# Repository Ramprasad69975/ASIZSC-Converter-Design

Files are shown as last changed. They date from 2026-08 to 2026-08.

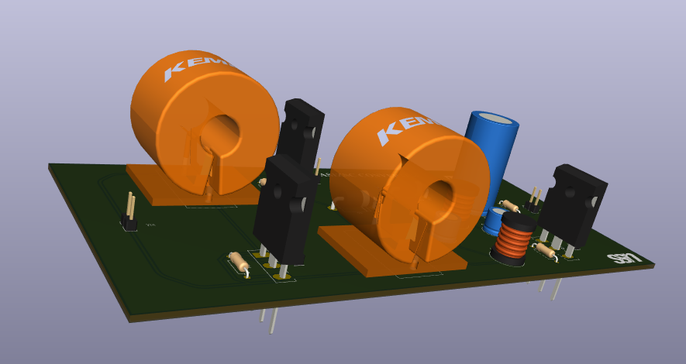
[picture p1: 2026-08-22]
PCB Images/3D Model.png

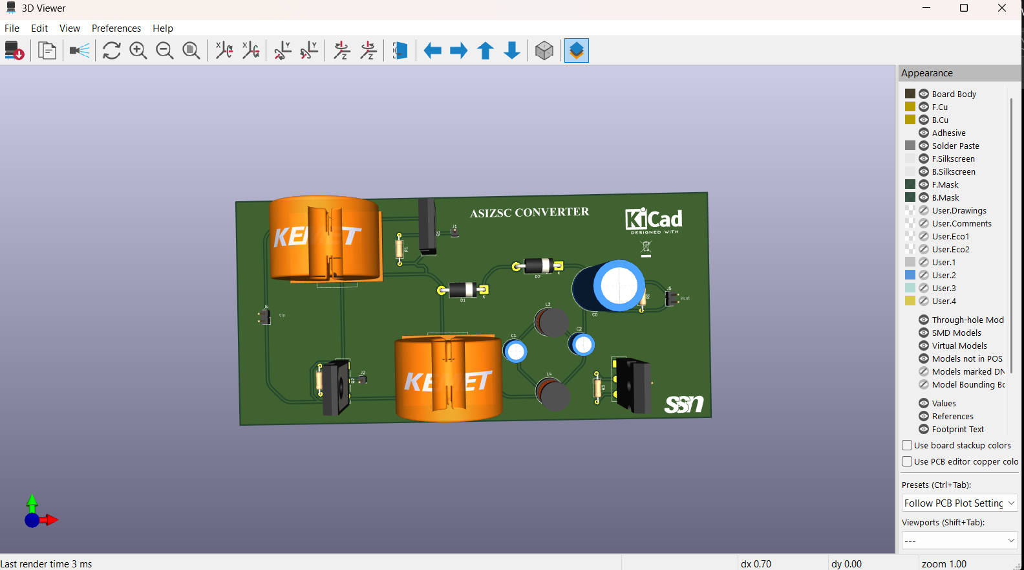
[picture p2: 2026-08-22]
PCB Images/3D view.png

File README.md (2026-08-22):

# ASIZSC Converter – Simulation & PCB Design

## Overview

This project documents the step-by-step development of a power electronics converter, starting from a basic Boost Converter and progressing toward the design of an Advanced Switched-Inductor Z-Source Converter (ASIZSC).

The work was carried out in three major stages:

1. Basic Boost Converter design and analysis
2. ASIZSC converter modelling and simulation in MATLAB/Simulink
3. Schematic and PCB design of the ASIZSC converter using KiCad

The project helped in understanding the transition from converter-level concepts and simulation to practical hardware-oriented PCB design.

---

## Project Development

### Stage 1 – Basic Boost Converter

The project initially started with the design and analysis of a conventional Boost Converter.

The basic converter was studied to understand:

- Boost converter operating principle
- Inductor and capacitor selection
- MOSFET switching
- Duty-cycle control
- Output voltage characteristics
- Continuous conduction operation
- Switching behaviour

The converter was modelled and analysed before moving toward the more advanced ASIZSC topology.

---

### Stage 2 – ASIZSC Converter Simulation

After studying the conventional Boost Converter, the project was extended to an **Advanced Switched-Inductor Z-Source Converter (ASIZSC)**.

The ASIZSC converter was modelled and simulated using **MATLAB/Simulink**.

The simulation involved:

- Switched-inductor network
- MOSFET switching stage
- Diode network
- Capacitor network
- Output filtering
- PWM-based switching
- Analysis of input and output behaviour

MATLAB/Simulink was used to study the converter operation and verify the circuit behaviour before proceeding to PCB development.

---

### Stage 3 – ASIZSC Schematic & PCB Design

After completing the converter-level simulation, the ASIZSC circuit was translated into a practical hardware design using **KiCad**.

The schematic was developed with:

- Three IRFP460 MOSFETs
- MUR640 diodes
- Switched-inductor networks
- Input and output capacitors
- Gate-driver interfaces
- Output filtering
- Load connection

The schematic was then converted into a PCB layout with consideration for component placement, power routing, high-current paths, and external gate-driver connections.

---

## Key Features

- Conventional Boost Converter study as the starting point
- Advanced Switched-Inductor Z-Source Converter topology
- MATLAB/Simulink converter simulation
- 3-MOSFET switching stage
- External gate-driver interface
- Custom footprints for large inductors
- Power-oriented PCB routing
- Through-hole and SMD components
- 3D PCB visualization
- Gerber files prepared for fabrication

---

## Hardware

- IRFP460 MOSFET × 3
- MUR640 diode × 2
- 80 µH inductors × 2
- 1 mH inductors × 2
- 33 µF capacitors × 2
- 330 µF output capacitor
- 144 Ω load resistor
- External gate-driver interface

---

## Tools Used

### Simulation
- MATLAB
- Simulink

### PCB Design
- KiCad Schematic Editor
- KiCad PCB Editor
- KiCad 3D Viewer
- KiCad Gerber Viewer

---

## Design Workflow

```text
Basic Boost Converter
        ↓
Converter Analysis
        ↓
ASIZSC Converter Development
        ↓
MATLAB/Simulink Simulation
        ↓
Circuit Schematic
        ↓
Footprint Assignment
        ↓
PCB Component Placement
        ↓
PCB Routing
        ↓
3D PCB Verification
        ↓
Gerber Generation

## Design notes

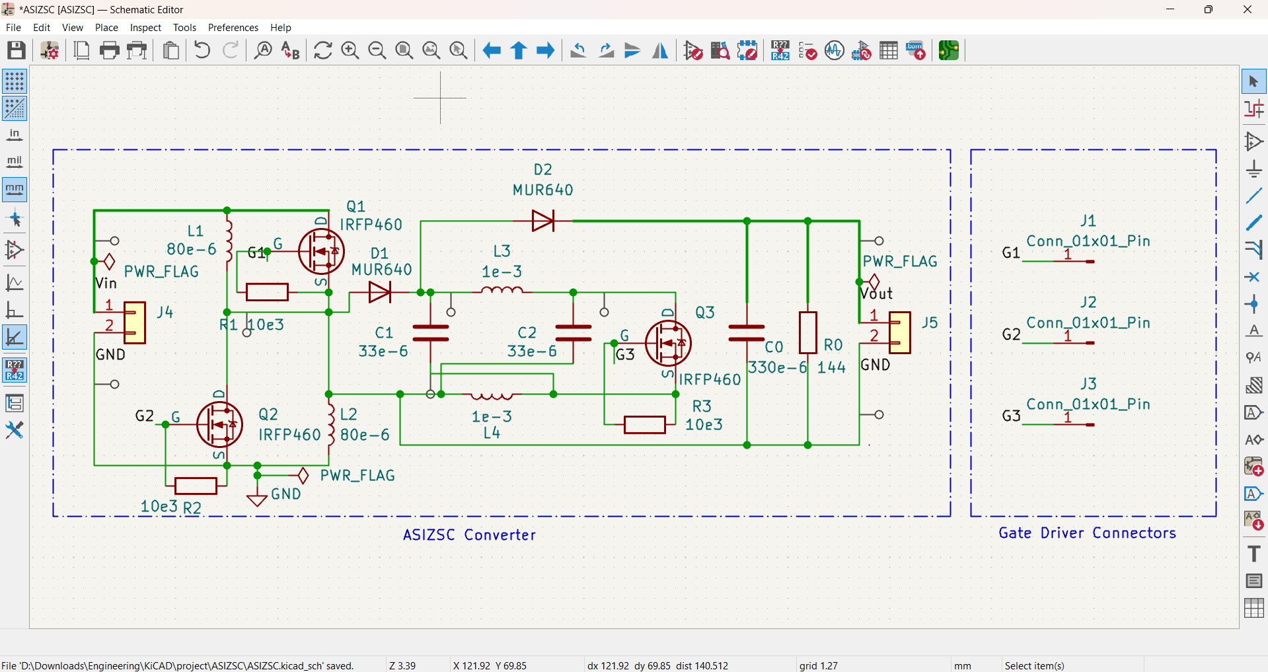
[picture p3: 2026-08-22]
PCB Images/Schematic diagram.png

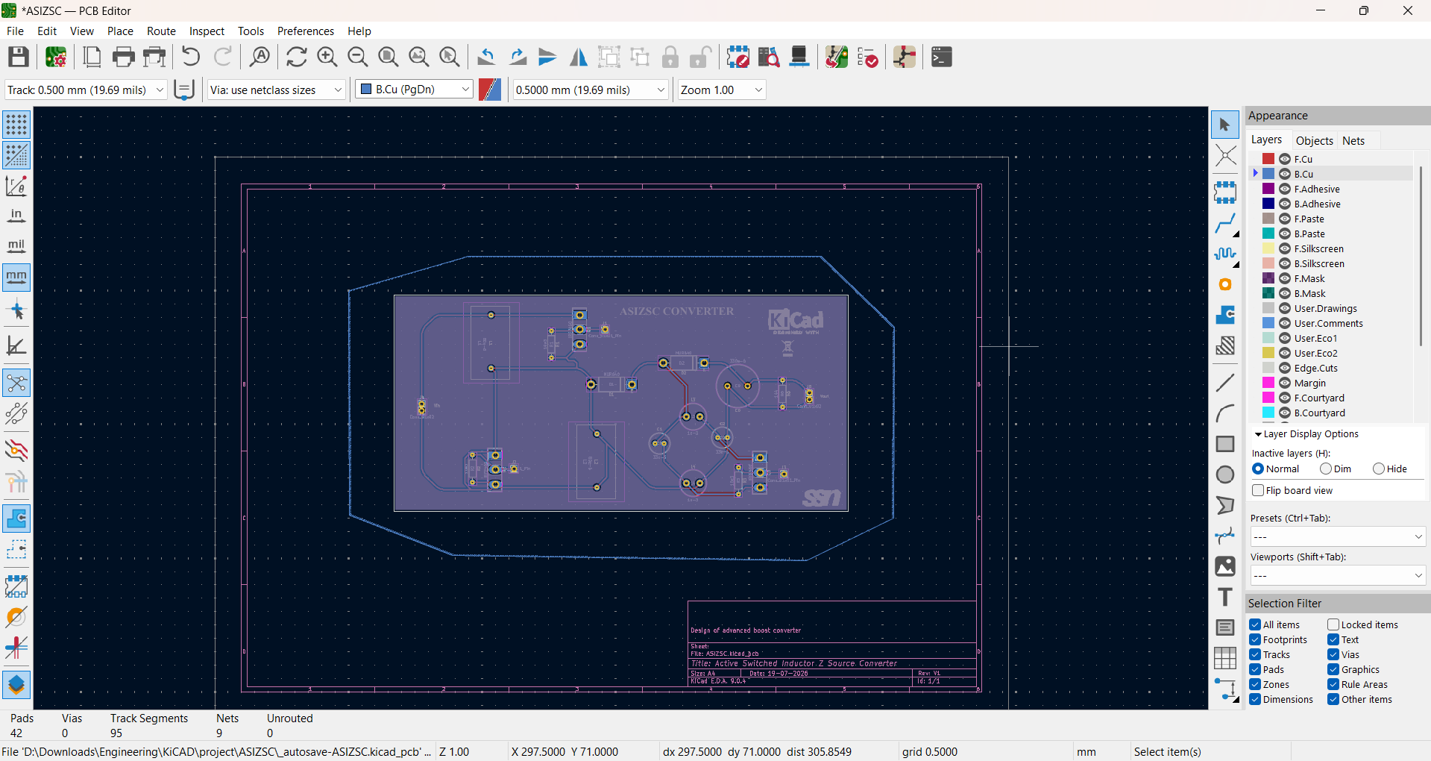
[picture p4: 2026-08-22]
PCB Images/PCB Design.png

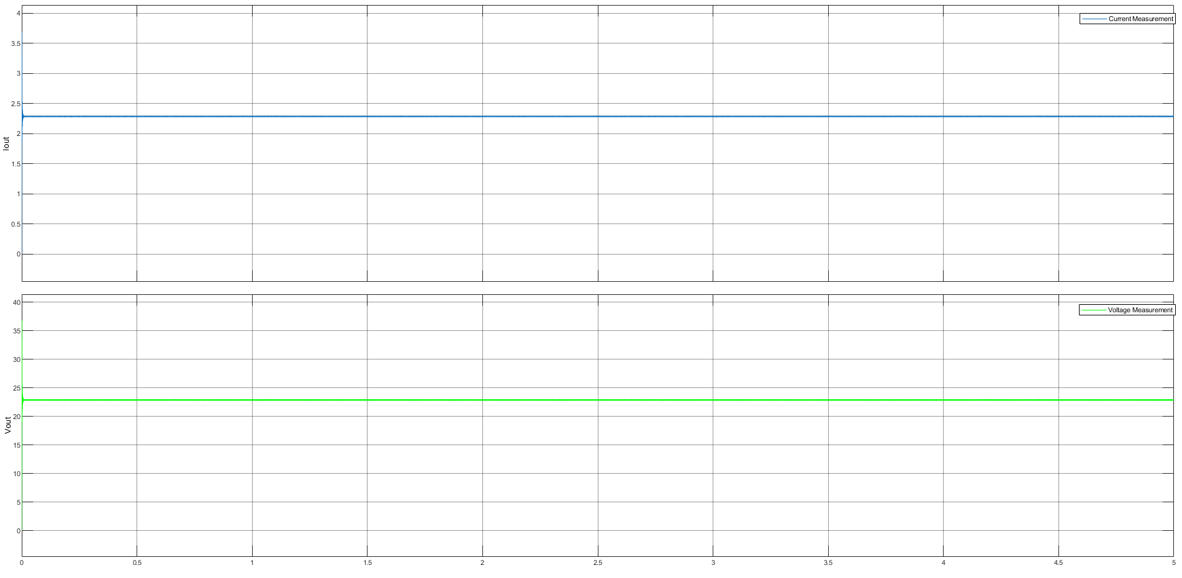
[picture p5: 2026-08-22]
Simulink_Output/Boost1.png

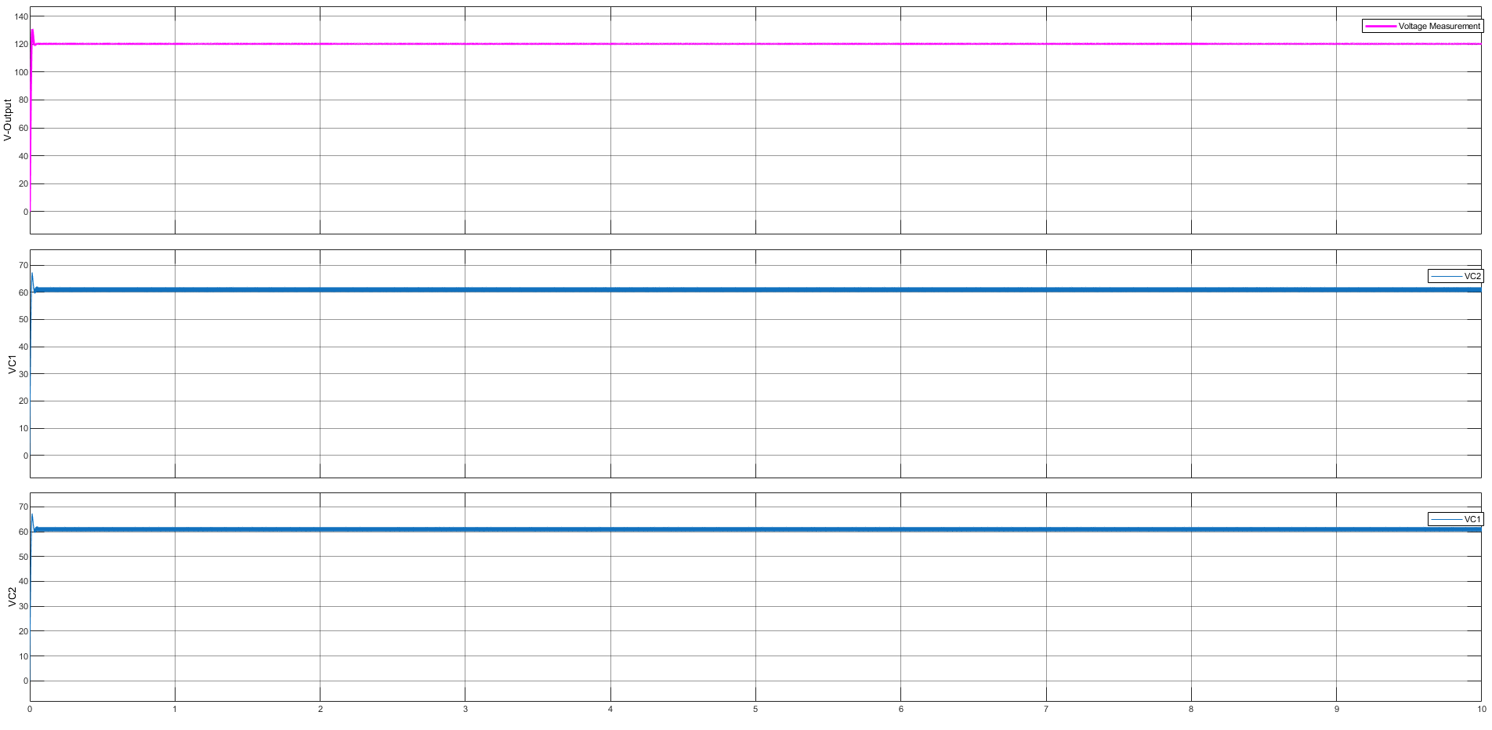
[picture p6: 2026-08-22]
Simulink_Output/ASIZSC.png

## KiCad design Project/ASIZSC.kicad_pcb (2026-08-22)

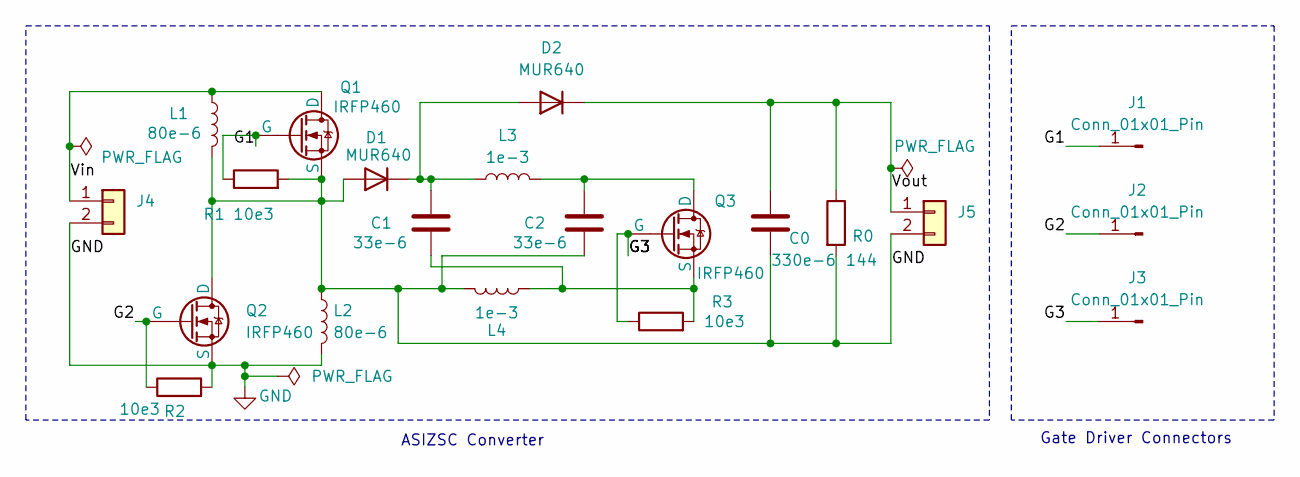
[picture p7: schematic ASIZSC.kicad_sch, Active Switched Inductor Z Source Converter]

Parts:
C0: 330e-6; C_Radial_D16.0mm_H31.5mm_P7.50mm
C1, C2: 33e-6; C_Radial_D8.0mm_H7.0mm_P3.50mm
D1, D2: MUR640; D_DO-201AD_P15.24mm_Horizontal
J1, J2, J3: Conn_01x01_Pin; PinHeader_1x01_P2.54mm_Vertical
J4, J5: Conn_01x02; PinHeader_1x02_P2.54mm_Vertical
L1, L2: 80e-6; L_THT_D35mm_P20mm
L3, L4: 1e-3; L_Radial_D10.0mm_P5.00mm_Fastron_07M
Q1, Q2, Q3: IRFP460; TO-247-3_Vertical
R0: 144; R_Axial_DIN0207_L6.3mm_D2.5mm_P10.16mm_Horizontal
R1, R2, R3: 10e3; R_Axial_DIN0207_L6.3mm_D2.5mm_P10.16mm_Horizontal

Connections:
/G1: J1.1, Q1.2 (G), R1.1
/G2: J2.1, Q2.2 (G), R2.1
/G3: J3.1, Q3.2 (G), R3.1
/Vin: J4.1, L1.1, Q1.1 (D)
/Vout: C0.1, D2.1 (K), J5.1, R0.1
GND: C0.2, C2.2, D1.2 (A), J4.2, J5.2, L1.2, L2.1, L2.2, L4.2, Q1.3 (S), Q2.1 (D), Q2.3 (S), R0.2, R1.2, R2.2
unnamed: C1.1, D1.1 (K), D2.2 (A), L3.1
unnamed: C2.1, L3.2, Q3.1 (D)
unnamed: C1.2, L4.1, Q3.3 (S), R3.2

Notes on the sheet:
Gate Driver Connectors
ASIZSC Converter

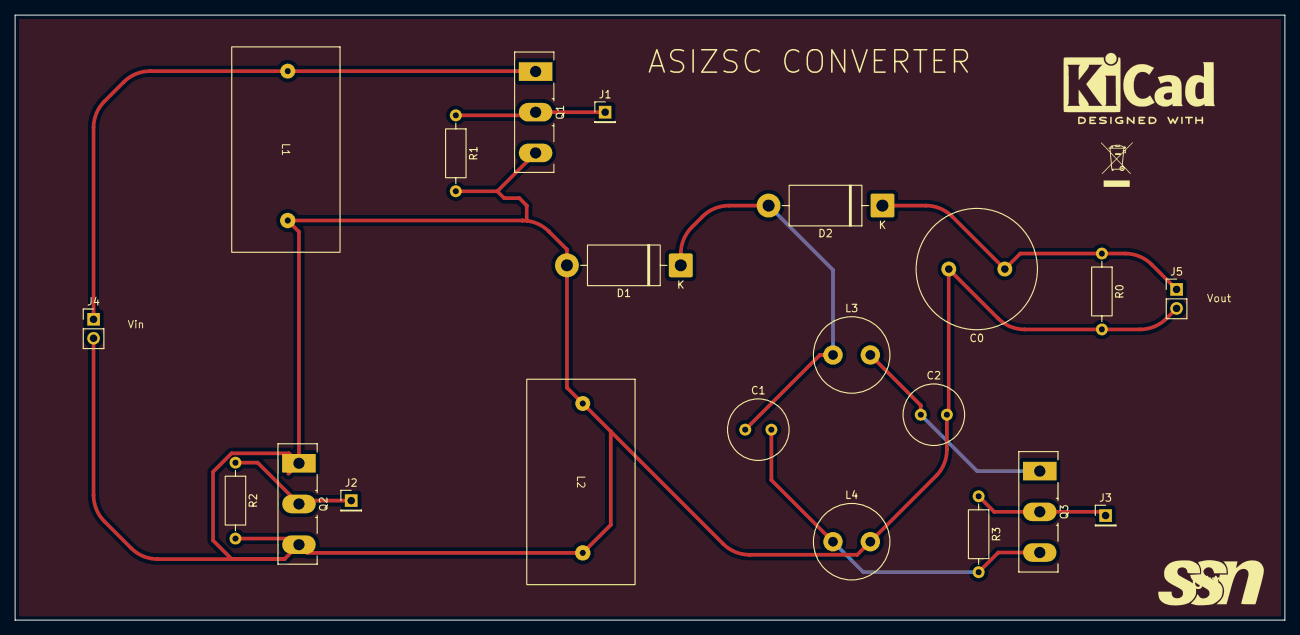
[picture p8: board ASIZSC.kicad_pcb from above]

Board: 2 copper layers, 170.0 x 81.0 mm, 21 parts (0 on the bottom side), 9 nets.

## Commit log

2026-08-22 Create circuit
2026-08-22 Rename Screenshot 2026-08-22 212910.png to PCB Images/Screenshot 2026-08-22 212910.png
2026-08-22 Rename Screenshot 2026-08-22 212942.png to PCB Images/Screenshot 2026-08-22 212942.png
2026-08-22 Rename Screenshot 2026-08-22 212926.png to PCB Images/Screenshot 2026-08-22 212926.png
2026-08-22 Rename Screenshot 2026-08-22 212958.png to PCB Images/Screenshot 2026-08-22 212958.png
2026-08-22 Rename Screenshot 2026-08-22 213045.png to PCB Images/Screenshot 2026-08-22 213045.png
2026-08-22 Rename Screenshot 2026-08-22 213054.png to PCB Images/Screenshot 2026-08-22 213054.png
2026-08-22 Rename Screenshot 2026-08-22 212910.png to Gerber 3D view.png
2026-08-22 Rename Screenshot 2026-08-22 212926.png to Gerber file.png
2026-08-22 Rename Screenshot 2026-08-22 212942.png to PCB Design.png
2026-08-22 Rename Screenshot 2026-08-22 212958.png to Schematic diagram.png
2026-08-22 Update PCB design in ASIZSC.kicad_pcb
    [ASIZSC.kicad_pcb]
2026-08-22 Create Schematic
